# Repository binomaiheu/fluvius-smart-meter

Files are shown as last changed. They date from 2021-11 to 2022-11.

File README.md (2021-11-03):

# Fluvius smart meter readout project

This is my version of a readout board for the Belgian smart energy meter deployed by Fluvius. The device contains 2 ports which allow the interested hobbyist to read out the real time energy consumption every sectond P1 and the full 4kHz waveform via the S1 port. This repo is for my own education as I shamelessly copied and adapted the work of Matthijs Kooijman and Willem Aandwiel, see links below for the originals !

## Links

Below is a collection of references with the original material upon which I based this **original project** : 
* https://willem.aandewiel.nl/index.php/2018/08/28/slimme-meter-uitlezer/
* https://opencircuit.nl/blog/Slimme-meter-uitlezer 

And a few links on **github** : 

* Decoder : https://github.com/matthijskooijman/arduino-dsmr
* Logger : https://github.com/mrWheel/DSMRlogger2HTTP
* https://mrwheel.github.io/DSMRloggerWS/

You can find a **python decoder** for the serial messages here : 
* https://github.com/jvhaarst/DSMR-P1-telegram-reader

The **specs** for the smart meter can be found here : 
* https://www.netbeheernederland.nl/_upload/Files/Slimme_meter_15_a727fce1f1.pdf
* https://www.fluvius.be/sites/fluvius/files/2019-07/1901-fluvius-technical-specification-user-ports-digital-meter.pdf
* https://www.fluvius.be/sites/fluvius/files/2019-12/e-mucs_h_ed_1_3.pdf

## Hardware

### P1 port pinout

The Fluvius meter P1 port uses an RJ12 connector with the following pinout.

| pin | function |
|-----|---|
| 1 | Power +5 V |
| 2 | Data Request |
| 3 | Data GND |
| 4 | n.c. |
| 5 | Data line |
| 6 | Power GND |

The protocol is `serial TTL` between 0 and 5 V, but with *polarity reversed*, meaning that 5V indicates a `0` and 0V indicates a `1`.

### Circuit board

The circuit in the `kicad/` subfolder is essentially based on the work of Willem Aandewiel (https://opencircuit.nl/blog/Slimme-meter-uitlezer) with some modifications of my own whilst getting to know KiCad. 

I'm using a Lolin D32 ESP board (https://www.wemos.cc/en/latest/d32/index.html) to readout & process the telegrams. For the footprint i installed the following library in KiCad : 

* https://github.com/pauls-3d-things/kicad-library

This contains both the schematic as well as the footprint for the Lolin D32 board. 

### Manufacturing

See :
* https://aisler.net  for in the EU manufacturing at reasonable price

### Power

For powering the esp32 I found this post on reddit : https://www.reddit.com/r/esp32/comments/bwgn1q/how_to_power_a_lolin_d32_externally_from_a_dc/, it presents 3 options (copy pasted): 

* *I figured it out with the help of [Dave Bird's Tech Note 097](https://www.youtube.com/watch?v=yZjpYmWVLh8) which explained how the on-board regulator can be disabled (open-circuit) by tying the EN pin to ground. This allows direct application of 3.3V onto the 3V pin, powering the board directly. Additionally, if EN is held low, a USB cable can be connected and serial comms continues to operate, because the CH340C has 3.3V supply. Power from the USB is shorted to ground via 100kohm resistor, which is no big deal.*
* *An alternative is to power at 4.2V via the battery connector. The TP4054 can take up to 7V on its BAT pin, and the charger won't enable unless the voltage drops below 4.2V, so one could also supply, say, 5V via this connector. The D2 diode will protect USB.*
* *One third option is to supply 5V via VBUS pin, ensuring it is as close as possible to the USB voltage (a difference of a few tenths of a volt may not cause any problems). If paranoid, a diode can be used to protect the USB supply.*

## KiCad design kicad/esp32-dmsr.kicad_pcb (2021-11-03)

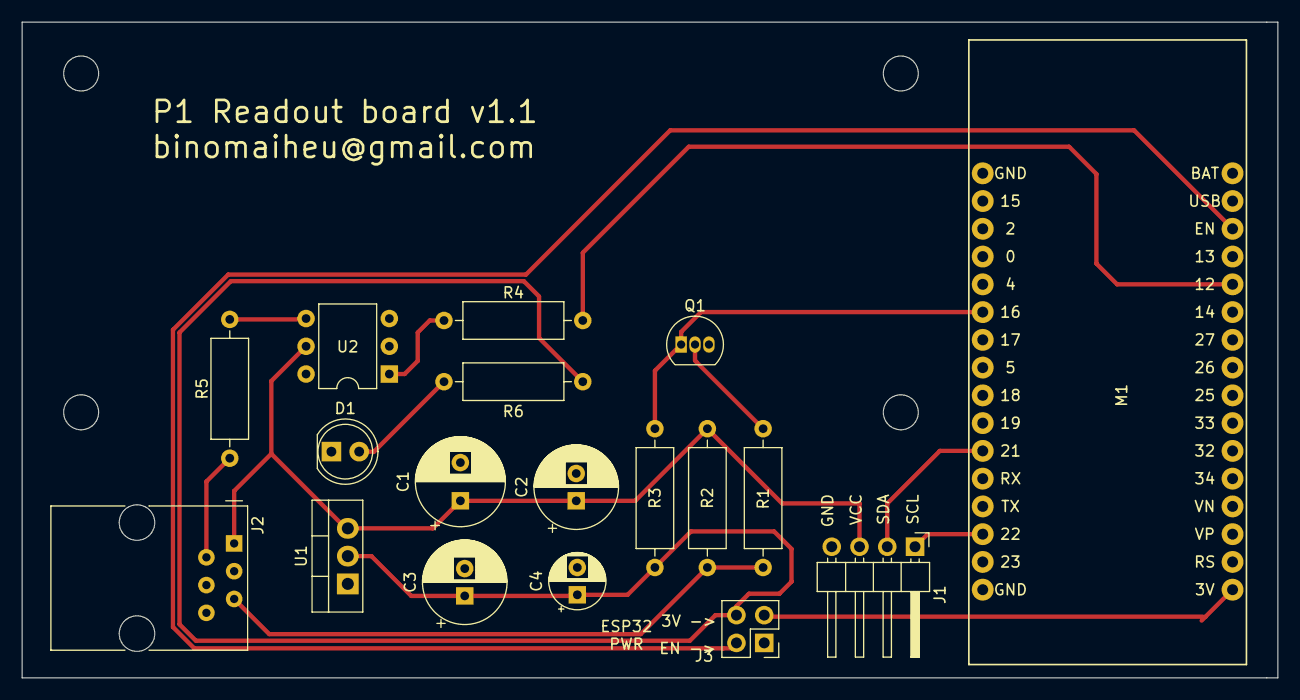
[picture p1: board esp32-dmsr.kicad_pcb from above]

Board: 2 copper layers, 114.9 x 60.0 mm, 18 parts (0 on the bottom side), 15 nets.

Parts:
C1: 1000 µF; CP_Radial_D8.0mm_P3.50mm
C2: 1 µF; CP_Radial_D7.5mm_P2.50mm
C3: 220 µF; CP_Radial_D7.5mm_P2.50mm
C4: 2.2 µF; CP_Radial_D5.0mm_P2.50mm
D1: LED; LED_D5.0mm
J1: LCD pin header; PinHeader_1x04_P2.54mm_Horizontal
J2: RJ12; RJ12_Amphenol_54601
J3: ESP32 Power; PinHeader_2x02_P2.54mm_Vertical
M1: LolinD32
Q1: BC547; TO-92_Inline
R1: 1 kOhm; R_Axial_DIN0309_L9.0mm_D3.2mm_P12.70mm_Horizontal
R2, R3: 2.2 kOhm; R_Axial_DIN0309_L9.0mm_D3.2mm_P12.70mm_Horizontal
R4, R6: 220 Ohm; R_Axial_DIN0309_L9.0mm_D3.2mm_P12.70mm_Horizontal
R5: 10 Ohm; R_Axial_DIN0309_L9.0mm_D3.2mm_P12.70mm_Horizontal
U1: LM1085-3.3; TO-220-3_Vertical
U2: 4N35; DIP-6_W7.62mm

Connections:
5V: C1.1, C2.1, J1.3, J2.1, R2.1, U1.3, U2.5
DRQ: J2.2, R5.2
GND: C1.2, C2.2, C3.2, C4.2, D1.1, J1.4, J2.3, J2.6, J3.1, M1.17, Q1.3, U1.1, U2.2
GPIO12: M1.5, R4.2
LCD_SCL: J1.1, M1.30
LCD_SDA: J1.2, M1.27
unnamed: C3.1, C4.1, J3.4, R3.1, R6.1, U1.2
unnamed: D1.2, R6.2
unnamed: J3.2, M1.3
unnamed: J3.3, M1.16
unnamed: Q1.2, R1.2
unnamed: R4.1, U2.1
unnamed: R5.1, U2.4
RX: M1.22, Q1.1, R3.2
TX: J2.5, R1.1, R2.2

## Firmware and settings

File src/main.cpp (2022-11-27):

#include <Arduino.h>
#include <WiFi.h>
#include <WiFiUdp.h>
#include <PubSubClient.h>
#include <NTPClient.h>
#include <IPAddress.h>

#undef USE_LCD
#ifdef USE_LCD
# include <LiquidCrystal_I2C.h>
#endif

#include <dsmr.h>
#include "arduino_secrets.h"


// =================================================================
// Defines
// =================================================================
#define ESP32_UART_PORT   2  // Using UART2 on the Lolin D32
#define DATA_ENABLE      12  // GPIO12 is connected to data enable

#define LEAP_YEAR(Y)     ( (Y>0) && !(Y%4) && ( (Y%100) || !(Y%400) ) )



// =================================================================
// Globals
// =================================================================
WiFiClient wifiClient;
WiFiUDP ntpUDP;
NTPClient  ntpClient(ntpUDP);
HardwareSerial SerialHW(ESP32_UART_PORT);
P1Reader reader(&SerialHW, DATA_ENABLE);

void callback(char *topic, byte* payload, unsigned int len);
PubSubClient mqttClient(MQTT_SERVER, MQTT_PORT, callback, wifiClient);

unsigned long tWiFiConnect;
unsigned long tMQTTConnect;

#ifdef USE_LCD
LiquidCrystal_I2C lcd(0x27, 16, 2);   
#endif

using MyData = ParsedData<
    /* String */ identification,
    /* String */ p1_version,
    /* String */ timestamp,
    /* String */ equipment_id,
    /* FixedValue */ energy_delivered_tariff1,
    /* FixedValue */ energy_delivered_tariff2,
    /* FixedValue */ energy_returned_tariff1,
    /* FixedValue */ energy_returned_tariff2,
    /* String */ electricity_tariff,
    /* FixedValue */ power_delivered,
    /* FixedValue */ power_returned,
    /* FixedValue */ electricity_threshold,
    /* uint8_t */ electricity_switch_position,
    /* uint32_t */ electricity_failures,
    /* uint32_t */ electricity_long_failures,
    /* String */ electricity_failure_log,
    /* uint32_t */ electricity_sags_l1,
    /* uint32_t */ electricity_sags_l2,
    /* uint32_t */ electricity_sags_l3,
    /* uint32_t */ electricity_swells_l1,
    /* uint32_t */ electricity_swells_l2,
    /* uint32_t */ electricity_swells_l3,
    /* String */ message_short,
    /* String */ message_long,
    /* FixedValue */ voltage_l1,
    /* FixedValue */ voltage_l2,
    /* FixedValue */ voltage_l3,
    /* FixedValue */ current_l1,
    /* FixedValue */ current_l2,
    /* FixedValue */ current_l3,
    /* FixedValue */ power_delivered_l1,
    /* FixedValue */ power_delivered_l2,
    /* FixedValue */ power_delivered_l3,
    /* FixedValue */ power_returned_l1,
    /* FixedValue */ power_returned_l2,
    /* FixedValue */ power_returned_l3,
    /* uint16_t */ gas_device_type,
    /* String */ gas_equipment_id,
    /* uint8_t */ gas_valve_position,
    /* TimestampedFixedValue */ gas_delivered_be>; // need the belgian variety..

struct Printer
{
  template <typename Item>
  void apply(Item &i)
  {
    if (i.present())
    {
      Serial.print(Item::name);
      Serial.print(F(": "));
      Serial.print(i.val());
      Serial.print(Item::unit());
      Serial.println();
    }
  }
};

void printWiFi(void)
{

  IPAddress ip = WiFi.localIP();
  long rssi = WiFi.RSSI();

  Serial.print(F("SSID: ")); 
  Serial.print(WiFi.SSID());
  Serial.print(F(", IP: "));
  Serial.print(ip);
  Serial.print(F(", RSSI: "));
  Serial.print(rssi);
  Serial.println(" dBm"); 
  
  return;
}

void startWiFi(void)
{
  if (WiFi.status() != WL_CONNECTED ) 
  {
    WiFi.begin(WIFI_SSID, WIFI_PASSWD);
  }
  return;
}

void callback(char *topic, byte* payload, unsigned int len )
{
  return;
}


String to_time_str(unsigned long secs) {
  unsigned long rawTime = secs;
  unsigned long hours = (rawTime % 86400L) / 3600;
  String hoursStr = hours < 10 ? "0" + String(hours) : String(hours);

  unsigned long minutes = (rawTime % 3600) / 60;
  String minuteStr = minutes < 10 ? "0" + String(minutes) : String(minutes);

  unsigned long seconds = rawTime % 60;
  String secondStr = seconds < 10 ? "0" + String(seconds) : String(seconds);

  return hoursStr + ":" + minuteStr + ":" + secondStr;
}


// Based on https://github.com/PaulStoffregen/Time/blob/master/Time.cpp
// currently assumes UTC timezone, instead of using this->_timeOffset
String to_isoformat(unsigned long secs) {
  unsigned long rawTime = secs / 86400L;  // in days
  unsigned long days = 0, year = 1970;
  uint8_t month;
  static const uint8_t monthDays[]={31,28,31,30,31,30,31,31,30,31,30,31};

  while((days += (LEAP_YEAR(year) ? 366 : 365)) <= rawTime)
    year++;
  rawTime -= days - (LEAP_YEAR(year) ? 366 : 365); // now it is days in this year, starting at 0
  days=0;
  for (month=0; month<12; month++) {
    uint8_t monthLength;
    if (month==1) { // february
      monthLength = LEAP_YEAR(year) ? 29 : 28;
    } else {
      monthLength = monthDays[month];
    }
    if (rawTime < monthLength) break;
    rawTime -= monthLength;
  }
  String monthStr = ++month < 10 ? "0" + String(month) : String(month); // jan is month 1  
  String dayStr = ++rawTime < 10 ? "0" + String(rawTime) : String(rawTime); // day of month  
  return String(year) + "-" + monthStr + "-" + dayStr + "T" + to_time_str(secs ? secs : 0) + "Z";
}



// =================================================================
// Setup
// =================================================================
void setup()
{
  Serial.begin(115200);
  SerialHW.begin(115200);

  // configure GPIO12 --> enable the datafeed
  pinMode(DATA_ENABLE, OUTPUT);
  digitalWrite(DATA_ENABLE, 0);

#ifdef USE_LCD
  lcd.init();               // initialize the lcd 16 cols, 2 rows
  lcd.clear();
  lcd.backlight();
#endif

  // start a read right away
  reader.enable(false);

  // starting wifi, need connection before continuing
  Serial.println(F("Starting WiFI"));
  startWiFi();
  tWiFiConnect = millis();
  while ( ( WiFi.status() != WL_CONNECTED ) && ( millis() - tWiFiConnect ) < 30000 ) 
  {
    delay(100);
  }
  if ( WiFi.status() != WL_CONNECTED ) {
    Serial.println("Cannot connect to WiFi, giving up... ");
    while(true)
    {}
  }
  printWiFi();

  // starting mqtt
  mqttClient.connect("P1reader");
  tMQTTConnect = millis();
  while ( ! mqttClient.connected() && ( millis() - tMQTTConnect ) < 30000 )
  {
    delay(100);
  }
  if ( ! mqttClient.connected() ) {
    Serial.println("Unable to connect to MQTT broker, giving up...");
    while(true)
    {}
  }
  Serial.println("Connected to MQTT broker...");

  return;
}


// =================================================================
// Loop
// =================================================================
void loop()
{

  /* ========================================================================
  *  WiFi management   
  * 
  *  if the wifi is not connected and the last connection attempt is more than 
  *  30 seconds ago... attempt to start the wifi agaion
  *  ==================================================================== */
  if ( ( WiFi.status() != WL_CONNECTED ) && ( millis() - tWiFiConnect ) > 30000 ) {
    Serial.println(F("WiFi not connected, connecting..."));
    startWiFi();
    tWiFiConnect = millis();
    delay(10);
  
    // ensure we get a valid NTP
    Serial.print(F("Updating time client..."));
    ntpClient.begin();
    while ( ! ntpClient.update() ) {
      Serial.print(".");
      ntpClient.forceUpdate();
    }
    Serial.println(F("OK"));
    Serial.println("Time recieved : " + ntpClient.getFormattedTime() );

    printWiFi();
  }

  /* ========================================================================
  *  MQTT Management
  *  ==================================================================== */
  if ( ( WiFi.status() == WL_CONNECTED ) &&
      ( ! mqttClient.connected() ) && 
      ( millis() - tMQTTConnect ) > 30000 ) {    
    if ( mqttClient.connect( MQTT_CLIENT, MQTT_USER, MQTT_PASSWD ) ) {
      Serial.println("Connected to MQTT server.");
    } else {
      Serial.print("Failed to connect with MQTT server, state ");
      Serial.println(mqttClient.state());
    }
    tMQTTConnect = millis();
  }


  if (reader.loop())
  {
    MyData data;
    String err;
    if (reader.parse(&data, &err))
    {
      // Parse succesful, print result
      data.applyEach(Printer());
   
#ifdef USE_LCD      
      lcd.clear();
      lcd.setCursor(0,0);
      //lcd.printf("V:%.2f, A:%.2f", data.voltage_l1.val(), data.current_l1.val() );
      lcd.printf("Power: %6.3f %s", data.power_delivered.val(), data.power_delivered::unit() );

      lcd.setCursor(0,1);
      lcd.printf("Gas  : %6.3f %s", data.gas_delivered_be.val(), data.gas_delivered_be::unit() );
#endif

      if ( mqttClient.connected() ) 
      {
        ntpClient.update();

        ntpClient.getFormattedTime();

        String payload = 
          "{\"dateObserved\": \"" + to_isoformat(ntpClient.getEpochTime()) + "\"" +
          ",\"power\":{\"value\":" + String(data.power_delivered.val(),3) + ",\"unit\":\"" + data.power_delivered::unit() + "\"}"
          ",\"voltage\":{\"value\":" + String(data.voltage_l1.val(),3) + ",\"unit\":\"" + data.voltage_l1::unit() + "\"}"
          ",\"current\":{\"value\":" + String(data.current_l1.val(),3) + ",\"unit\":\"" + data.current_l1::unit() + "\"}"        
          ",\"gas\":{\"value\":" + String(data.gas_delivered_be.val(),3) + ",\"unit\":\"" + data.gas_delivered_be::unit() + "\"}"
        + "}";
        // Serial.println(payload);

        String chan = MQTT_CHANNEL + String("/") + MQTT_CLIENT + String("/value");
              
        if ( ! mqttClient.publish( chan.c_str(), payload.c_str()) ) {
          Serial.println(F("-- MQTT publish failed..."));
        }
      }






    }
    else
    {
      // Parser error, print error
      Serial.println(err);
    }

  }

  mqttClient.loop();
}

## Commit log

2021-10-22 added kicad gitignore
2021-11-03 added powering options
2021-11-03 version 1.1, as ordered
    [esp32-dmsr.kicad_pcb]
